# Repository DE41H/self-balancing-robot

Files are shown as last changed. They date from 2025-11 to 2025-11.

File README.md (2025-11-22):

# 🤖 Self-Balancing Robot

**A 4-person team project for ASME Probation.**

This repository contains all the code, documentation, and design files for our two-wheeled self-balancing robot. Our goal is to create a stable, responsive robot using a PID control system.

###  STATUS: 🚧 In-Progress

---

## 🛠️ Key Features

* **Stable Balancing:** Uses a PID controller to maintain balance on two wheels.
* **Sensor:** Uses gyroscope data for an accurate orientation estimate.
* **[Remote PID Tuning]:** PID tuning via WiFi/Bluetooth through mobile app.
* **[3D Printed]:** 3D printed chassis, wheels, brackets, optical disc.

---

## 🔌 Hardware Stack

* **Microcontroller:** ESP32-C3
* **Gyro Sensor:** MPU6050
* **Motors:** GA12-N20 DC Gear Motors
* **Motor Driver:** TB6612FNG
* **Battery:** 2S 7.4V LiPo Battery
* **Chassis:** 3D Printed
* **Wheels:** 3D Printed
* **Encoder:** Groove Coupler
* **Buck Converter:** LM2596

---

## 📦 Software & Libraries

* **Main Language:** C++ (Arduino Framework)

---

## 🤝 Our Team

* **[@DE41H]** - Sreyash Satpathy
* **[@IronMan1405]** - Dakshesh Nankani
* **[@PranayS216]** - Pranay
* **[@navneetgithubasdf]** - Navneet

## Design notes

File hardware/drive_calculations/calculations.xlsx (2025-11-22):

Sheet: Drivetrain_Calc
 | Inputs | Calculations
 | coeff fr. | chassis mass(kg) | Bot voltage | Electronics mass (kg) | total bot mass (kg)
bot info | 0.8 | 0.04 | 12 | 0.03 | 0.35
 | wheel dia(m) | no. of wheels | mass (kg)
wheel info | 0.1 | 2 | 0.03
 | rated voltage | stall current(A) per motor | Free RPM @ rated V | No.of Motors | mass per motor (kg) | Rated Torque(N-m) | Stall torque (N-m) | Ratio | Top speed (m/s)
Motor info (GA12-N20) | 6 | 1 | 100 | 2 | 0.01 | 0.1962 | 1.5696 | 10 | 0.5235987756
 | C-rating | Capacity (mAh) | Max Cont. Current (A) | mass (kg) | Nominal Voltage (V)
Battery info (2S-LiPo) | 30 | 850 | 25.5 | 0.2 | 7.4
 | Current Drawn (A)
 | MCU (ESP-32) | IMU (MPU-6050) | Motor Driver (logic) |  |  |  | Total Current Draw | Runtime (h) | Runtime (min)
Power Info | 0.15 | 0.005 |  |  |  |  | 2.155 | 0.3944315545 | 23.66589327
 | speed(m/s) | max acceleration(m/s^2) | Torque (N-m) | Traction Limit Force (N)
desired specs | 1 | 1 | 0.035 | 2.7468
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

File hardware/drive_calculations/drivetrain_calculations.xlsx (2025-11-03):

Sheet: Drivetrain_Calc
 | Inputs | Calculations
 | coeff fr. | mass(kg) | Bot voltage |  | Torque (N-m) | Traction Limit Force (N)
bot info | 0.8 | 1.5 | 12 |  | 0.15 | 11.772
 | wheel dia(m) | no. of wheels
wheel info | 0.1 | 2
 | rated voltage | stall current(A) per motor | Free RPM @ rated V | No.of Motors | Stall torque | Ratio | Top speed (m/s)
Motor info (GA12-N20) | 12 | 1 | 200 | 2 | 1.5696 | 10 | 1.047197551
 | C-rating | Capacity (mAh) | Max Cont. Current
Battery info | 30 | 850 | 25.5
 | Current Drawn (A)
 | MCU (ESP-32) | Gyro (MPU-6050) | Motor Driver (logic) |  | Total Current Draw | Runtime (h)
Power Info | 0.15 | 0.005 |  |  | 2.155 | 394.4315545
 | desired speed(m/s) | desired max acceleration(m/s^2)
 | 1 | 1

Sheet: V_RPM
Supply Voltage | RPM
3 | 50
6 | 100
12 | 200

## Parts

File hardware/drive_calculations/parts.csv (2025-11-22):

<<<<<<< HEAD
Part,Type,Quantity,Price,Weight,Link,Status,Notes
MPU-6050,IMU,1,₹169.00,5.00g,https://robu.in/product/mpu-6050-gyro-sensor-2-accelerometer/,In stock,
GA12-N20,Motor,1,₹259.00,12.00g,https://robu.in/product/n20-12v-200-rpm-micro-metal-gear-motor/,In stock,
ESP32,MCU,1,₹257.00,10.00g,https://robu.in/product/esp32-c3-development-board-with-soldering/,In stock,
TB6612FNG,Motor Driver,1,₹161.00,22.00g,https://robu.in/product/motor-driver-tb6612fng-module-performance-ultra-small-volume-3-pi-matching-performance-ultra-l298n,In stock,
N/A,N/A,0,₹0.00,0.00g,N/A,N/A,
N/A,N/A,0,₹0.00,0.00g,N/A,N/A,
Total,Sum,4,₹846.00,49.00g,N/A,Sum,
=======
Part,Type,Quantity,Price,Link,Status,Notes
MPU-6050,IMU,1,₹169.00,https://robu.in/product/mpu-6050-gyro-sensor-2-accelerometer/,In stock,Most standard and cost efficient option available
GA12-N20,Motor,2,₹239.00,https://robu.in/product/n20-6v-100-rpm-micro-metal-gear-box-dc-motor-2/,In stock,Provides enough torque and rpm to balance the robot
ESP32,MCU,1,₹257.00,https://robu.in/product/esp32-c3-development-board-with-soldering/,In stock,Has excess processing power to handle the PID loop
TB6612FNG,Motor Driver,1,₹161.00,https://robu.in/product/motor-driver-tb6612fng-module-performance-ultra-small-volume-3-pi-matching-performance-ultra-l298n/,In stock,Very efficient motor driver
2S1P Li-Ion,Battery,1,₹576.00,https://robu.in/product/18650-li-ion-2200mah-7-4v-2s1p-protected-battery-pack-2c/,In stock,"Standard choice, sufficient to power all our components"
LM2596,Buck Converter,1,₹41.00,https://robu.in/product/lm2596s-dc-dc-buck-converter-power-supply/,In stock,Buck converter required to step down battery voltage to use with ESP
Photoelectric Sensor,Encoder,2,₹66.00,https://robu.in/product/correlation-photoelectric-infrared-count-sensor-module/#tab-description,In stock,Groove Coupler acts as a motor encoder to calculate motor RPM
Total,Sum,9,"₹1,814.00",N/A,Sum,Overall these parts are expected to work well together
>>>>>>> origin/main

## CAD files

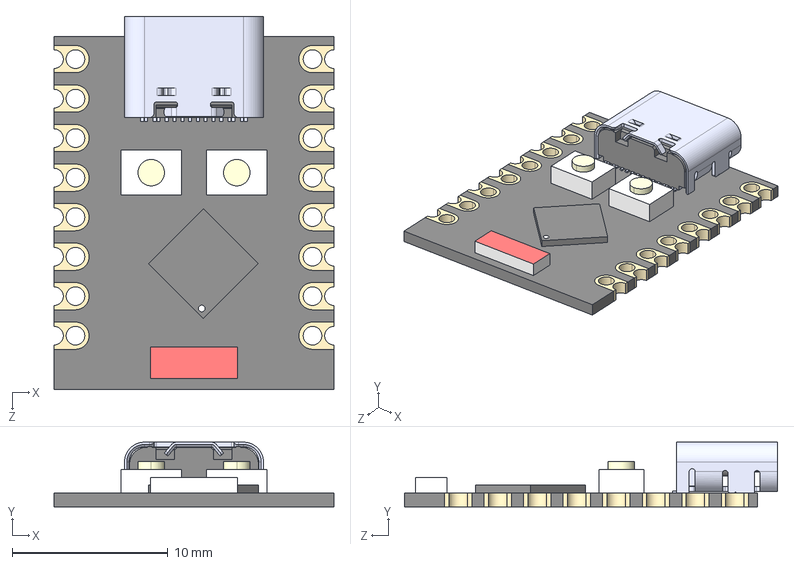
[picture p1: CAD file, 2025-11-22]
hardware/schematic/self-balancing-robot/ESP32-C3_SUPERMINI_TH/ESP32-C3_SUPERMINI_TH.step
18.0 x 4.16 x 24.0 mm
Board c3mini
USB C
components (other)^ESP32-C3 SuperMini

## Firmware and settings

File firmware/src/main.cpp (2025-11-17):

#include <Arduino.h>
#include <gyro.hpp>
#include <motor.hpp>
#include <pid_controller.hpp>
#include <config.hpp>

static TaskHandle_t taskHandle;

Gyro gyro = Gyro();
PIDController balance = PIDController(Config::BALANCE_KP, Config::BALANCE_KI, Config::BALANCE_KD, Config::BALANCE_MIN, Config::BALANCE_MAX);
PIDController turn = PIDController(Config::TURN_KP, Config::TURN_KI, Config::TURN_KD, Config::TURN_MIN, Config::TURN_MAX);
PIDController speed = PIDController(Config::SPEED_KP, Config::SPEED_KI, Config::SPEED_KD, Config::SPEED_MIN, Config::SPEED_MAX);

unsigned int lastEncoderCountA = 0;
unsigned int lastEncoderCountB = 0;
float filteredSpeed = 0.0f;
int lastPwmA = 0;
int lastPwmB = 0;

void IRAM_ATTR update() {
    struct Gyro::Data input;

    if (xQueueReceive(gyro.getDataQueue(), &input, pdMS_TO_TICKS(Config::MAX_WAIT_MS)) != pdTRUE || abs(input.pitch) > Config::DEADMAN_ANGLE) {
        A.setPWM(0);
        B.setPWM(0);
        Motor::stby(true);

        balance.reset();
        speed.reset();
        turn.reset();

        return;
    }

    unsigned int currentEncoderCountA = A.getEncoderCount();
    unsigned int currentEncoderCountB = B.getEncoderCount();

    int ticksA = currentEncoderCountA - lastEncoderCountA;
    int ticksB = currentEncoderCountB - lastEncoderCountB;

    lastEncoderCountA = currentEncoderCountA;
    lastEncoderCountB = currentEncoderCountB;

    int directionA = (lastPwmA >= 0) ? 1 : -1;
    int directionB = (lastPwmB >= 0) ? 1 : -1;

    float rawSpeedA = ticksA * directionA;
    float rawSpeedB = ticksB * directionB;
    float rawSpeed = (rawSpeedA + rawSpeedB) / 2.0f;
    
    filteredSpeed = (Config::SPEED_ALPHA * filteredSpeed) + ((1.0f - Config::SPEED_ALPHA) * rawSpeed);
    float targetPitch = speed.compute(-filteredSpeed, 0.0f);

    struct Gyro::Data output = {balance.compute(input.pitch, targetPitch + Config::MECHANICAL_OFFSET), turn.compute(input.yaw, 0.0f)};

    int pwmA = (int) (output.pitch + output.yaw);
    int pwmB = (int) (output.pitch - output.yaw);

    A.setPWM(pwmA);
    B.setPWM(pwmB);

    lastPwmA = pwmA;
    lastPwmB = pwmB;
}

void loop() {
    
}

void taskLoop() {
    while (true) {
        update();
    }
}

void taskTrampoline(void *pvParameters) {
    taskLoop();

    vTaskDelete(NULL);
}

void setup() {
    if (!gyro.begin() || !Motor::begin()) {
        return;
    }

    BaseType_t taskCreated = xTaskCreatePinnedToCore(
        taskTrampoline,
        "Main Task",
        Config::MAIN_TASK_STACK_SIZE,
        NULL,
        Config::MAIN_TASK_PRIORITY,
        &taskHandle,
        Config::MAIN_TASK_CORE_ID
    );
    if (taskCreated != pdPASS) {
        Serial.println("Failed to create motor task!");
        return;
    }
}

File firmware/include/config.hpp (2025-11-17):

#pragma once
#include <Adafruit_MPU6050.h>


namespace Config {
    static constexpr unsigned int SAMPLE_FREQ_HZ = 200;
    static constexpr unsigned int SAMPLE_TIME = 1000 / SAMPLE_FREQ_HZ;

    static constexpr mpu6050_accel_range_t ACCEL_RANGE = MPU6050_RANGE_8_G;
    static constexpr mpu6050_gyro_range_t GYRO_RANGE = MPU6050_RANGE_500_DEG;
    static constexpr mpu6050_bandwidth_t FILTER_BAND = MPU6050_BAND_94_HZ;

    static constexpr unsigned int GYRO_TASK_STACK_SIZE = 4096;
    static constexpr unsigned int GYRO_TASK_PRIORITY = 10;
    static constexpr unsigned int GYRO_TASK_CORE_ID = 0;
    static constexpr unsigned int GYRO_CALIBRATION_SAMPLES = 500;
    static constexpr unsigned int GYRO_CALIBRATION_DELAY_MS = 5;
    static constexpr unsigned int WIRE_CLOCK = 400000;
    static constexpr unsigned int SDA_PIN = 0;
    static constexpr unsigned int SCL_PIN = 0;

    static constexpr unsigned int MOTOR_A_PWM_PIN = 0;
    static constexpr unsigned int MOTOR_A_IN1_PIN = 0;
    static constexpr unsigned int MOTOR_A_IN2_PIN = 0;
    static constexpr unsigned int MOTOR_A_ENC_PIN = 0;
    static constexpr unsigned int MOTOR_A_PWM_CHAN = 0;

    static constexpr unsigned int MOTOR_B_PWM_PIN = 0;
    static constexpr unsigned int MOTOR_B_IN1_PIN = 0;
    static constexpr unsigned int MOTOR_B_IN2_PIN = 0;
    static constexpr unsigned int MOTOR_B_ENC_PIN = 0;
    static constexpr unsigned int MOTOR_B_PWM_CHAN = 0;

    static constexpr unsigned int MINIMUM_PWM = 0;
    static constexpr unsigned int PWM_FREQUENCY = 20000;
    static constexpr unsigned int PWM_RESOLUTION = 8;
    static constexpr unsigned int PWM_LIMIT = (1 << PWM_RESOLUTION) - 1;
    static constexpr unsigned int STBY_PIN = 0;
    static constexpr unsigned int ENCODER_PPR = 20;
    static constexpr float RPM_FACTOR = (60.0f * Config::SAMPLE_FREQ_HZ) / ENCODER_PPR;

    static constexpr float SPEED_KP = 0.0f;
    static constexpr float SPEED_KI = 0.0f;
    static constexpr float SPEED_KD = 0.0f;
    static constexpr float SPEED_MIN = -8.0f;
    static constexpr float SPEED_MAX = 8.0f;
    static constexpr float SPEED_ALPHA = 0.95f;

    static constexpr float BALANCE_KP = 0.0f;
    static constexpr float BALANCE_KI = 0.0f;
    static constexpr float BALANCE_KD = 0.0f;
    static constexpr float BALANCE_MIN = -255.0f;
    static constexpr float BALANCE_MAX = 255.0f;

    static constexpr float TURN_KP = 0.0f;
    static constexpr float TURN_KI = 0.0f;
    static constexpr float TURN_KD = 0.0f;
    static constexpr float TURN_MIN = -100.0f;
    static constexpr float TURN_MAX = 100.0f;

    static constexpr unsigned int MAIN_TASK_STACK_SIZE = 4096;
    static constexpr unsigned int MAIN_TASK_PRIORITY = 5;
    static constexpr unsigned int MAIN_TASK_CORE_ID = 0;

    static constexpr float DEADMAN_ANGLE = 70.0f;
    static constexpr unsigned int MAX_WAIT_MS = 20;

    static constexpr float MECHANICAL_OFFSET = 0.0f;
};

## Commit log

2025-11-03 Added initial draft of drivetrain calculations
    [drivetrain_calculations.xlsx]
2025-11-03 updated drive_calculations
    [drivetrain_calculations.xlsx]
2025-11-03 added motor datasheet
2025-11-03 made modifications to drivetrain calc
    [drivetrain_calculations.xlsx]
2025-11-03 Update and rename drive_calculations - Drivetrain_Calc.csv to drive_calculationscsv
2025-11-03 Fix filename extension for drive_calculations.csv
    [drive_calculations.csv]
2025-11-03 Update and rename drive_calculations.csv to alculations.csv
    [alculations.csv]
2025-11-03 Fix file path for calculations.csv
    [calculations.csv]
2025-11-03 added parts.ods file
    [parts.ods]
2025-11-03 added parts.csv
    [parts.csv]
2025-11-05 Drivetrain calculations Final (#2)
    * Added initial draft of drivetrain calculations
    * updated drive_calculations
    * added motor datasheet
    * made modifications to drivetrain calc
    * Add files via upload
    * Update and rename drive_calculations - Drivetrain_Calc.csv to drive_calculationscsv
    * Fix filename extension for drive_calculations.csv
    * added datasheets for possible parts
    * Update and rename drive_calculations.csv to alculations.csv
    * Fix file path for calculations.csv
    * added parts.ods file
    * added parts.csv
    * Rename drivetrain_calculations.xlsx to calculations.xlsx
    * added discrete weight calculations
    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
    [calculations.csv, calculations.xlsx, parts.csv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]
2025-11-05 Merge parts.csv and update part details
    Resolved merge conflict and updated part links and notes.
    [parts.csv]
2025-11-07 created gyro module for getting IMU readings
2025-11-08 added gyro and motor modules
2025-11-08 better gyro module
2025-11-08 improved error handling in gyro module
2025-11-08 improved case convention
2025-11-08 added working motor module
2025-11-12 new and improved gyro module
2025-11-13 changed control module to pid module
2025-11-15 added motor controlling module
2025-11-15 reduced hardcoded parameters in gyro module
2025-11-15 reduced hardcoding in motor module
2025-11-15 added extra failsafe to motor module
2025-11-16 prototype code
2025-11-16 bug fixes and performance improvements
    [main.cpp]
2025-11-16 swapped out all double variables with float
    [main.cpp]
2025-11-17 added a failsafe incase the bot falls
    [main.cpp]
2025-11-17 setup default limits for PID
2025-11-19 Schematic (#3)
    * added schematic
    * Removed schematic backups from tracking
    * added schematics
    [ESP32-C3_SUPERMINI_TH.step, self-balancing-robot.kicad_pcb, self-balancing-robot.kicad_sch]
